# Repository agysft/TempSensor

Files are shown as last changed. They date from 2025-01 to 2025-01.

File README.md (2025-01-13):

# Temperature and humidity logger

This is a prototype of a device that records temperature and humidity to an SD card every hour.  
これは１時間毎に温度と湿度をSDカードに記録する装置の試作です。  
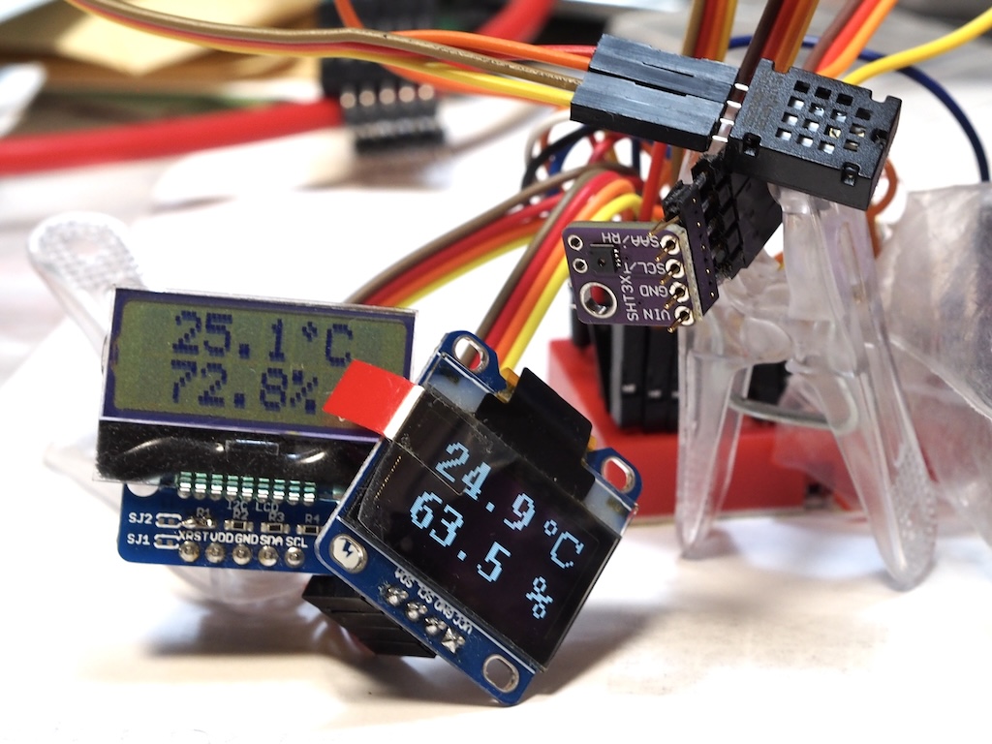
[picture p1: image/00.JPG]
  
It is actually a thermo-hygrometer to control the temperature of leopard geckos. It is intended to be hooked up to a breeding case.  
実はヒョウモントカゲモドキの温度管理をするための温湿度計です。
飼育ケースに引っ掛けて使うことを想定しています。
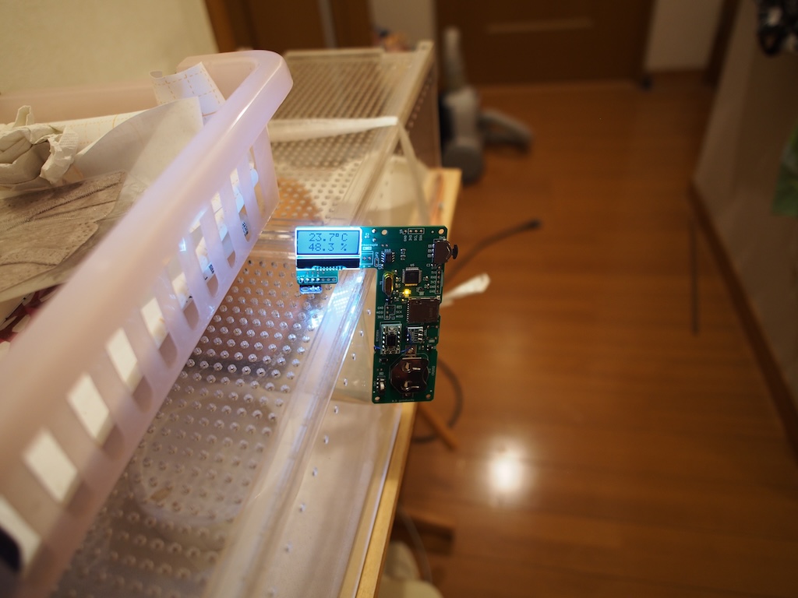
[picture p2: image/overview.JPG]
  
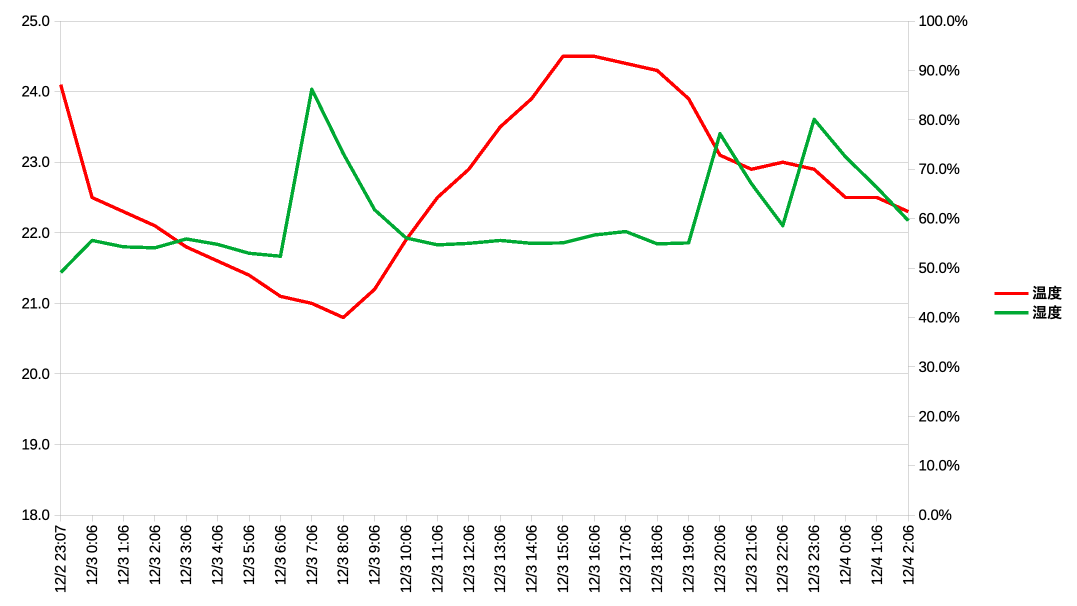
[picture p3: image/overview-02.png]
  
OLEDs can also be mounted. I chose Arduino base because it has a library of fonts.  
OLEDも載せられる様にしてます。その時フォントとか選びたいのでライブラリがあるArduinoベースにしました。  
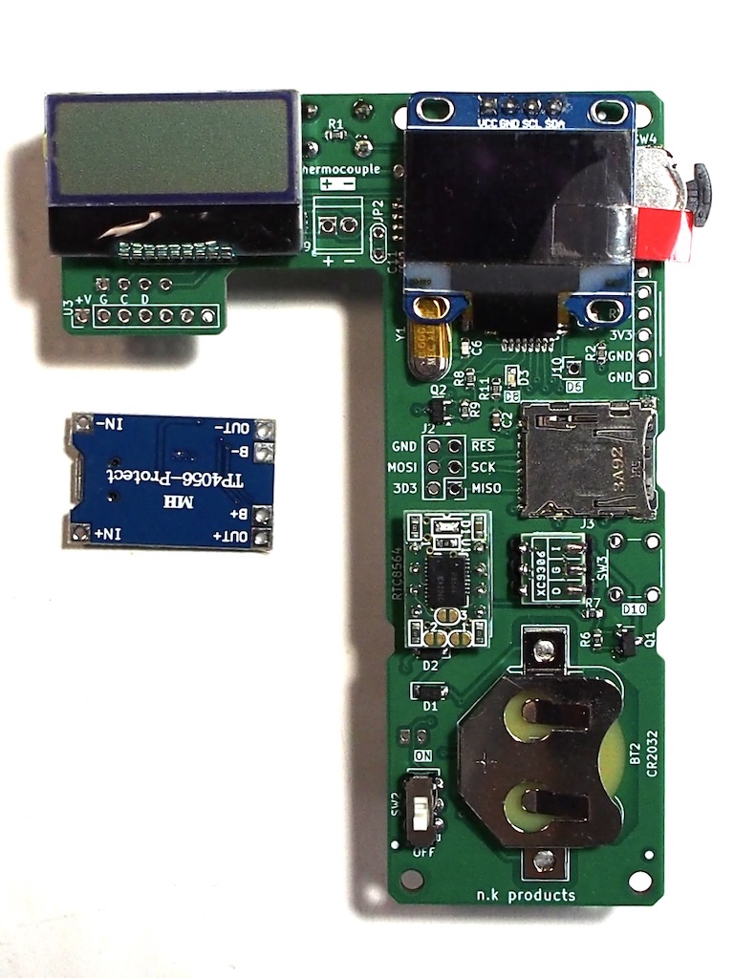
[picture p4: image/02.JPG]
  
The program was written in Arduino IDE. The schematic is written in KiCAD and the printed circuit board is made. The structure was made with a 3D printer.  
プログラムはArduino IDEで書きました。回路図はKiCADで書き、プリント基板を作っています。構造物は3Dプリンターで作りました。  

<image src="image/04-01.png" width="320px">
<image src="image/04-02.png" width="320px">
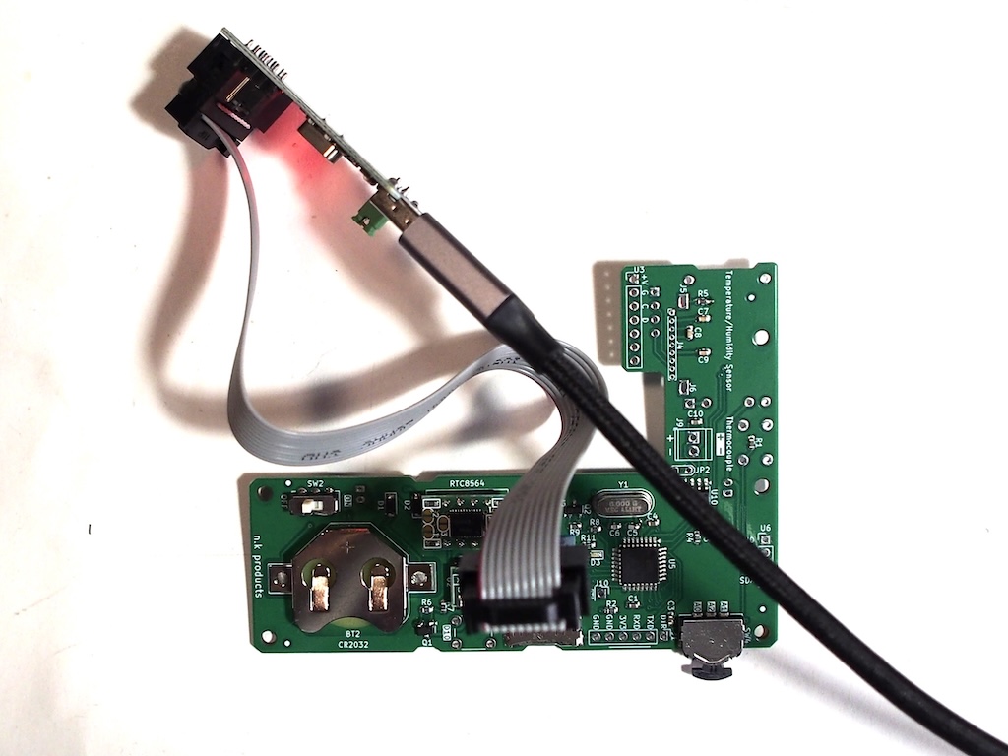
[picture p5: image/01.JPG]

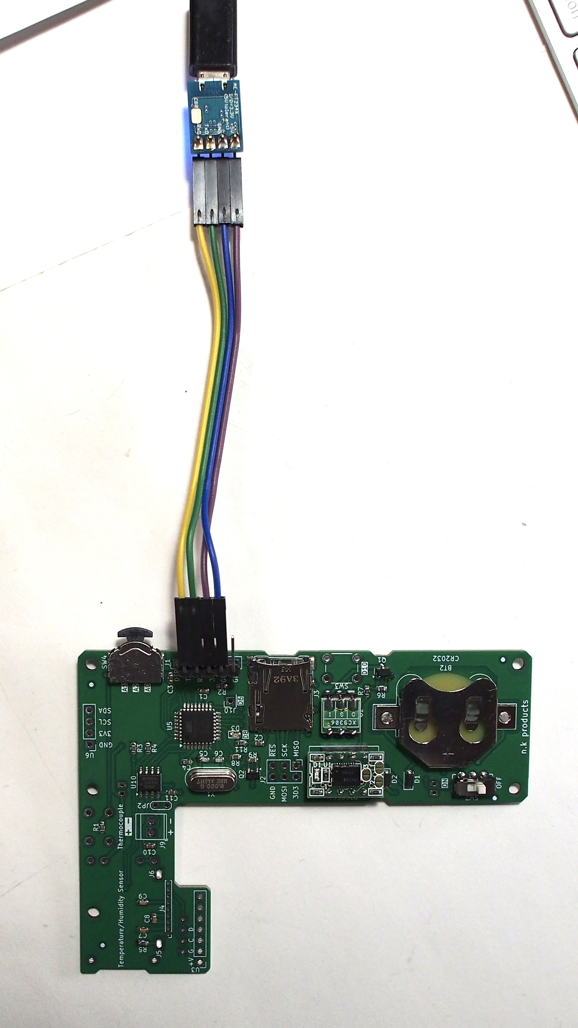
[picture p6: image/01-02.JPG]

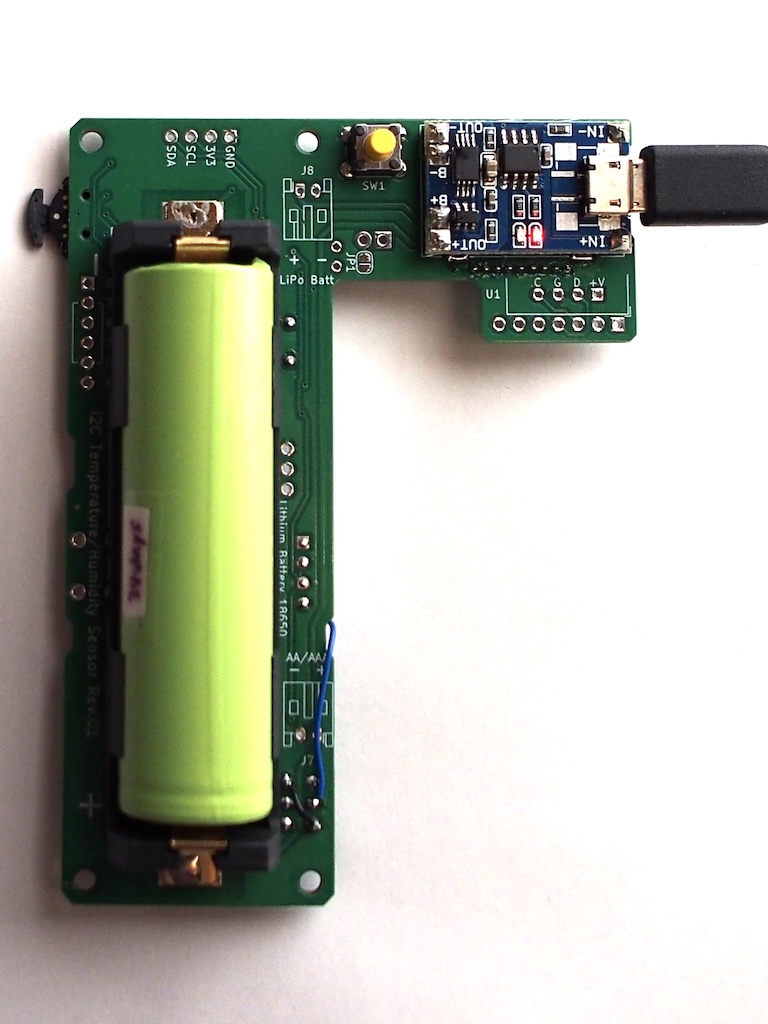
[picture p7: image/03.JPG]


---

* [schematics](schematics/TempHumiSensor.pdf)

The system is powered on and off at regular intervals by RTC and automatically turns off when the measurement is finished.  
RTCで一定時間毎に電源を入れて計測し、計測終了したら自動で電源を切る仕組みです。 

1. RTCで1時間毎に/INT信号を出す。RTC sends /INT signal every hour.
2. /INT信号がLowになると、Q1がOn=電源On。When the /INT signal goes Low, Q1 turns On = power supply On.
3. 電源がOnになると温湿度を測定する。  When the power supply is turned On, the temperature and humidity are measured.  
4. 測定終了したら/INTをクリア、Q1がOff=電源Off。  When measurement is completed, /INT is cleared and Q1 turns Off = power is Off.  

```mermaid
flowchart LR
    A[SHT31] -->|I2C| B[ATMEGA328P-AU]
    B --> |I2C|C[LCD]
    B -->|I2C| D[OLED]
    B -->|SPI| E[SD]
    F[MAX31855] -->|SPI| B
    G[LiPo Batt] -->|4V| H[Swich] --> I[Buck-Boost Converter] --- |3.3V|B
    J[RTC] --> |/INT|H
```

---

[modification document 改造資料]  
The P-ch MOS FET that turns the power supply On/Off could not be turned Off. The reason was that PD2 on the ATmega328P was pulling /POW low. I had to worry about leakage current flowing when the microcontroller was turned off.  
電源をOn/OffするP-ch MOS FETがOFFできなかった。理由はATmega328PのPD2が/POWをLowに引っ張っていたためです。マイコンの電源が切れている時は漏れ電流が流れる事を気にしなきゃならなかった。  
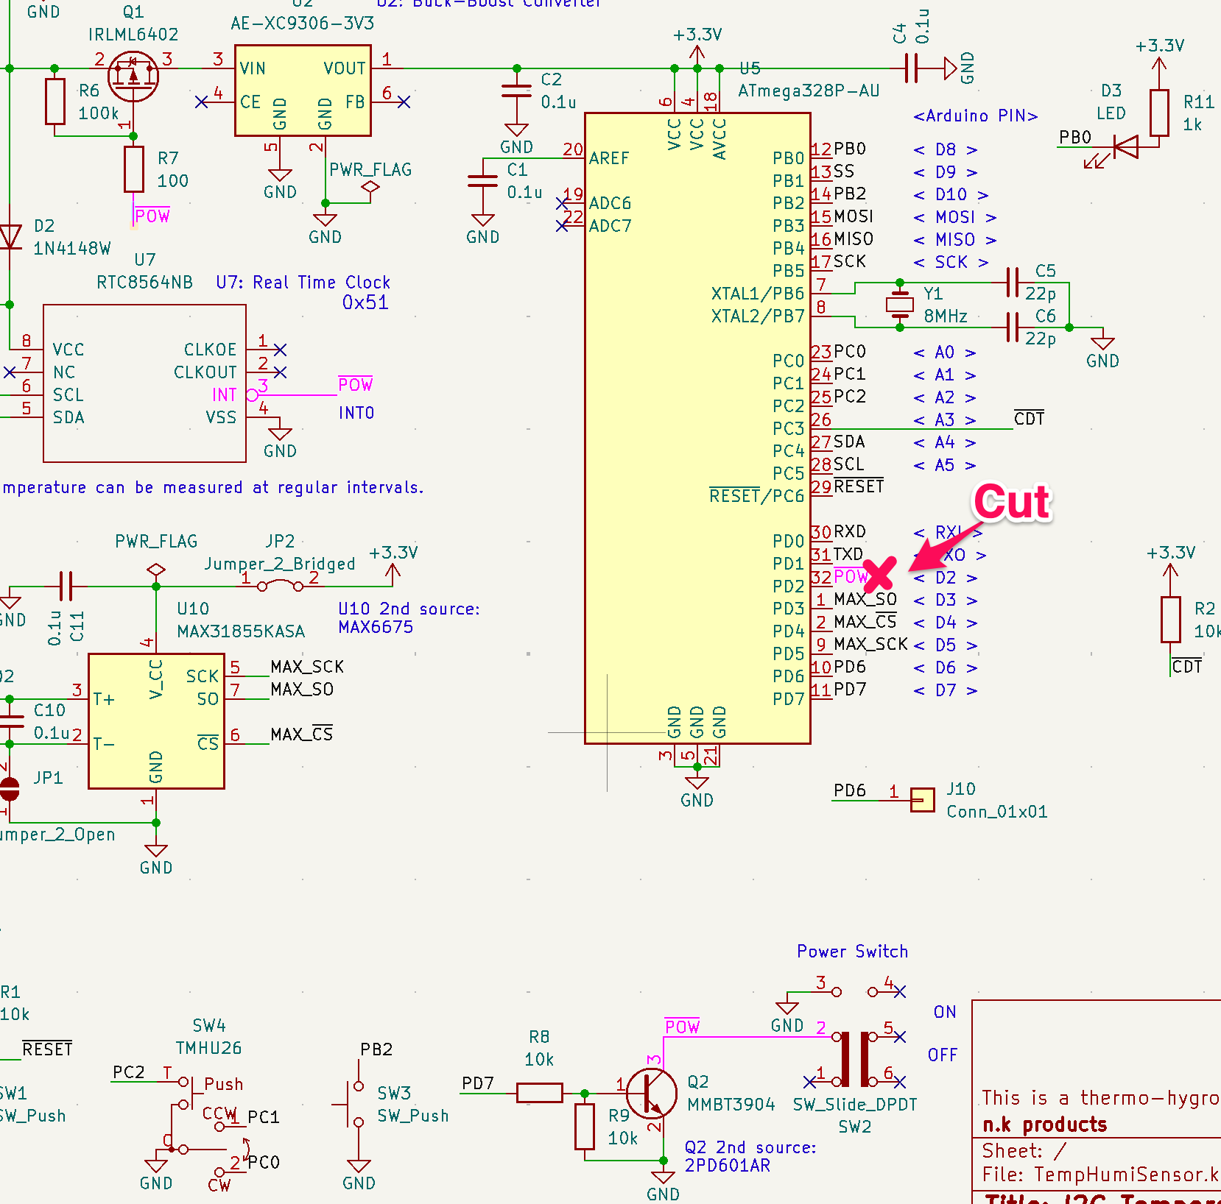
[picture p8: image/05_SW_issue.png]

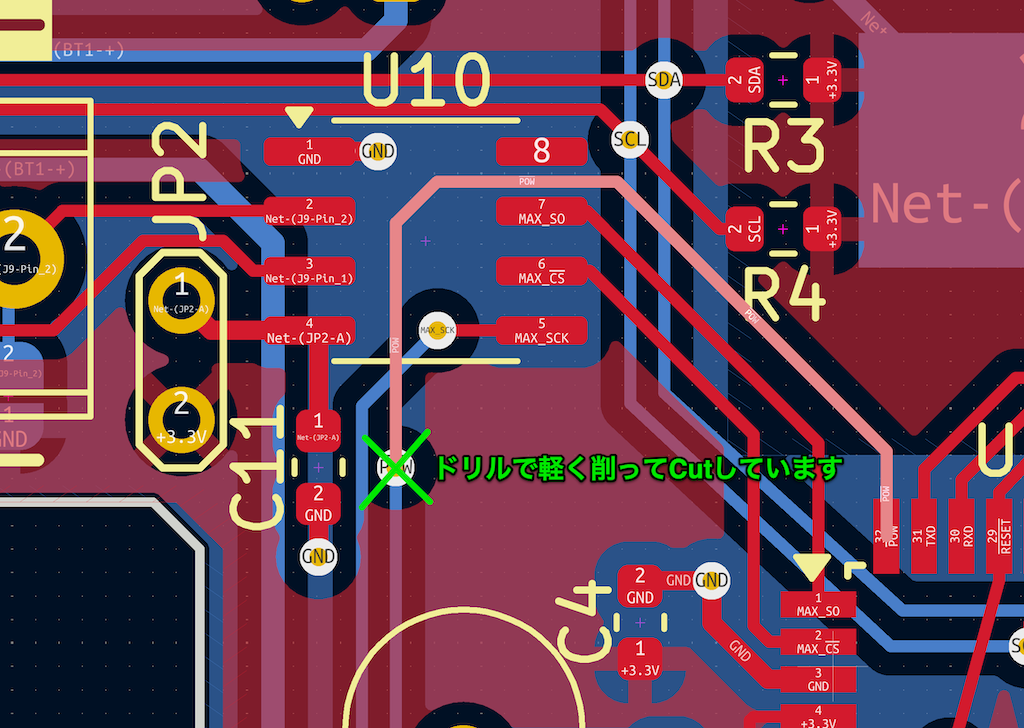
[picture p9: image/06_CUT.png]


---

[state diagram 状態遷移]
```mermaid
stateDiagram-v2
    s1: Power On
    s2: Write Temp/Humi data to SD card when TE=Enable
    s3: Display T/H sensor
    s4: Display Thermocouple
    s5: Display Clock
    s6: Adjust Clock
    s7: Timer Enable
    s8: Timer Disable
    s9: Shift Digit Up
    s10: Increment
    s11: Decrement
    s1 --> s2
    s2 --> s3
    s3 --> s4: push center-button
    s4 --> s5: push center-button
    s5 --> s3: push center-button
    s5 --> s6: long-push center-button
    s6 --> s5: long-push center-button
    s6 --> s9: push center-button
    s9 --> s6
    s6 --> s10: push up-button
    s10 --> s6
    s6 --> s11: push up-button
    s11 --> s6
    s7 --> s8: long-push push-button
    s8 --> s7: long-push push-button
```

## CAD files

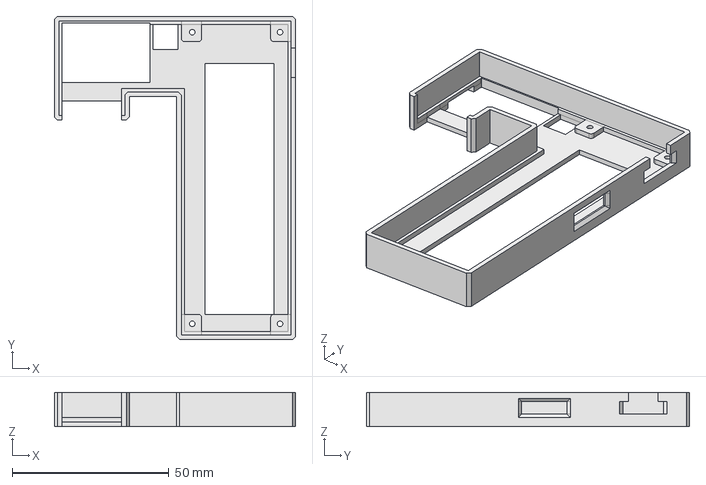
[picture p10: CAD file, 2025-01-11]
3D/tempSensor.FCStd
77.0 x 103.0 x 11.0 mm

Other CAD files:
3D/tempSensor-Body.stl

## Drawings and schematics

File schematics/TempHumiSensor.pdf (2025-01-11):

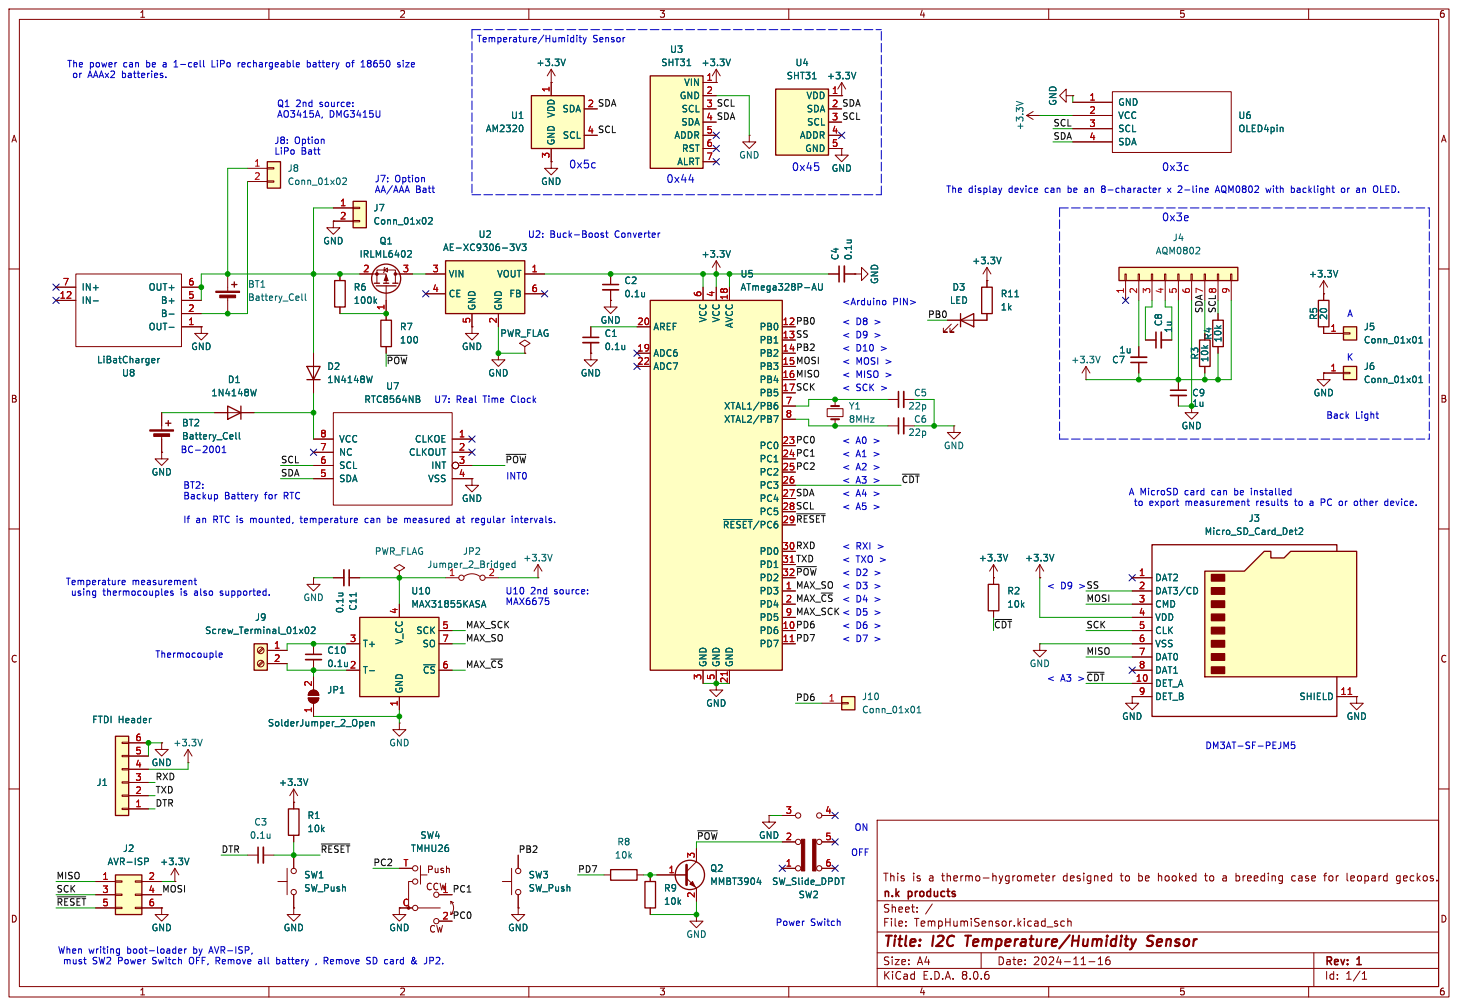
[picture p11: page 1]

3 SCL 4 +3.3V U3 SHT31VIN 1 GND 2 SCL 3 SDA 4 ADDR 5 RST 6 ALRT 7 +3.3V U4 SHT31VDD 1 SDA 2 SCL 3 ADDR 4 GND 5GND

BC-2001 BT2: Backup Battery for RTC

4 SCK 5 ~{CS}6 SO 7 0.1u C11 GND GND GND

4 SCK 5 ~{CS}6 SO 7 U10 MAX31855KASA CCW

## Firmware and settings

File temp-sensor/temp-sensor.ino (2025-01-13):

#include <Wire.h>
#include <SPI.h>
#include <SD.h>
//#include <EEPROM.h>
#include "RTC8564.h"

//#define SENSOR_MAX6675 //comment MAX31855
// Initialize the Thermocouple
// set pin of MAX31855,MAX6675
#define MAXDO   3
#define MAXCS   4
#define MAXCLK  5
#ifdef SENSOR_MAX6675
  #include "max6675.h"
  MAX6675 thermocouple(MAXCLK, MAXCS, MAXDO);
#else
  #include "Adafruit_MAX31855.h"
  Adafruit_MAX31855 thermocouple(MAXCLK, MAXCS, MAXDO);
#endif

float temperatureData = 0.0;  // Temperature

/*** OLED Definition ***/
//#define DISPLAY_OLED //comment No Use OLED
#ifdef DISPLAY_OLED
  #include <U8g2lib.h>
  U8G2_SSD1306_128X64_NONAME_1_HW_I2C u8g2(U8G2_R0, /* reset=*/ U8X8_PIN_NONE);
  #define OLED_ADDR 0x3C
#endif

/*** Enumerated I2C addresses ***/
uint8_t Enumerated_I2C_addresses[8];

/*** SD Card Definition ***/
#define SS_pin 9  // D9

/*** Switches Definition ***/
#define QTY_of_switches 4
#define sw_Upper 0
#define sw_Lower 1
#define sw_Center 2
#define sw_Push 3
struct SwitchStatus {
  uint8_t PinNumber;
  int Counter;
  bool Pressed;
  bool Released;
  bool LongPressing;
  bool LongPressed;
};
volatile struct SwitchStatus SW[QTY_of_switches];

/*** LCD ***/
#define LCD_ADDR 0x3e
char DisplayData[20] = "n.k     products    ";
void writeLCDData(byte t_data){
  Wire.beginTransmission(LCD_ADDR);
  Wire.write(0x40);
  Wire.write(t_data);
  Wire.endTransmission();
  delay(1);
}
void writeLCDCommand(byte t_command){
  Wire.beginTransmission(LCD_ADDR);
  Wire.write(0x00);
  Wire.write(t_command);
  Wire.endTransmission();
  delay(1);
}
void init_LCD(){
  delay(400);
  writeLCDCommand(0x38);
  writeLCDCommand(0x39);
  writeLCDCommand(0x14);
  writeLCDCommand(0x7c);
  writeLCDCommand(0x55);
  writeLCDCommand(0x6c);
  delay(250);
  writeLCDCommand(0x38);
  writeLCDCommand(0x01);
  writeLCDCommand(0x0c);
  delay(1);
}
void LCD_xy(uint8_t x, uint8_t y){
    writeLCDCommand(0x80 + 0x40 * y + x);
}
void LCD_str2(const char *c) {
    unsigned char wk;
    int i;
    for (i=0;i<8;i++){
        wk = c[i];
        if  (wk == 0x00) break;
        writeLCDData(wk);
    }
    delay(1);
}
void LCD_char(char wk) {
  writeLCDData(wk);
  delay(1);
}
void LCD_char_with_Cursor(uint8_t x, uint8_t y, char wk) {
  writeLCDCommand(0x80 + 0x40 * y + x);
  writeLCDData(wk);
  LCD_cursor_Left();
  delay(1);
}
void LCD_clear(){
  writeLCDCommand(0x01);
  delay(1);
}
void LCD_cursor_on(){
  writeLCDCommand(0b00001111);
  //writeLCDCommand(0b00010000);  // bit3=S/C=L, bit2=R/K=L
  delay(1);
}
void LCD_cursor_off(){
  writeLCDCommand(0b00001100);
  delay(1);
}
void LCD_cursor_Left(){
  writeLCDCommand(0b00010000);
  delay(1);
}
void LCD_cursor_Right(){
  writeLCDCommand(0b00010100);
  delay(1);
}

/*** SHT31 ***/
#define SHT31_ADDR 0x44
int TData, HData;  //Temp data , Humi data
uint8_t THData[6];
/*
THData[0] temperature high
THData[1] temperature low
THData[2] CRC temperature
THData[3] humidity high
THData[4] humidity low
THData[5] CRC humidity
 */
void readSHT31(){
  Wire.beginTransmission(SHT31_ADDR);
  Wire.write(0x24);
  Wire.write(0x00);
  Wire.endTransmission();
  delay(30);  // 12=NG, 13=Good
  Wire.requestFrom(SHT31_ADDR, 6);
  for (int i=0; i<6; i++){
    THData[i] = Wire.read();
  }
}
void getTH(){
  long lTData, lHData;
  readSHT31();
  lTData = 256 * THData[0] + THData[1];
  lTData = -450 + (1750 * lTData) / 65535;
  TData = (int)lTData;
  lHData = (long)(THData[3]);
  lHData = (lHData << 8) | THData[4];
  lHData = (1000 * lHData) / 65535;
  HData = (int)lHData;
}
void DispTH(){
  byte x, x2;
  float T2Data,H2Data;
  getTH();
  #ifdef DISPLAY_OLED
    if (isAaddressExistInI2C(OLED_ADDR)){
      u8g2.clearBuffer();
      u8g2.firstPage();
      do {
        /* all graphics commands have to appear within the loop body. */
        T2Data = (float)TData; dtostrf(T2Data/10,4,1,DisplayData);
        x = u8g2.drawStr(0,25,DisplayData);
        x2 = u8g2.drawStr(x,25," C");//"\xB0"); 
        //u8g2.drawStr(x+x2,15,"C");
        H2Data = (float)HData; dtostrf(H2Data/10,4,1,DisplayData);
        x = u8g2.drawStr(0,63,DisplayData); u8g2.drawStr(x,63," %");
      } while ( u8g2.nextPage() );
      u8g2.sendBuffer();
    }
  #endif
  sprintf(DisplayData, "%3d.%1d C\0", TData /10, abs(TData %10) );//"%3d.%1d\xDF\x43", TData /10, abs(TData %10) );
  LCD_xy(0,0); LCD_str2( DisplayData );
  sprintf(&DisplayData[8], " %2d.%1d %%\0", HData /10, HData %10 );
  LCD_xy(0,1); LCD_str2( &DisplayData[8] );
}

/*** Read Thermocouple ***/

void ReadThermocouple(void) {
  float temp = 0.0;  // Temperature
  for (byte i = 0; i < 5; i++) {
      do {
      temperatureData = thermocouple.readCelsius();
    }while(isnan(temperatureData)) ;
        
    temp = temp + temperatureData;
    delay(20);
  }
  #ifdef SENSOR_MAX6675
    temperatureData = (temp / 5.0)*0.99 -2.5;  //MAX6675
    //if ( temperatureData > 200 ) temperatureData-10;
  #else
    temperatureData = (temp / 5.0)*1.00-1.0;  //MAX31855
  #endif
}

/*** RTC8564 ***/
#define RTC8564_SLAVE_ADRS 0x51
bool TimerEnable = false;
uint8_t date_time[7];
/*date_time[0] = 0x00;//seconds
date_time[1] = 0x45;//minutes
date_time[2] = 0x17;//hours
date_time[3] = 0x28;//days
date_time[4] = 0x04;//weekdays
date_time[5] = 0x11;//months/century
date_time[6] = 0x24;//years*/
void writeCommandToRTC(uint8_t reg1, uint8_t dat1){
  Wire.beginTransmission(RTC8564_SLAVE_ADRS);
  Wire.write(reg1);
  Wire.write(dat1);
  Wire.endTransmission();
}
uint8_t readRegDataFromRTC(uint8_t reg1){
  Wire.beginTransmission(RTC8564_SLAVE_ADRS);
  Wire.write(reg1);
  Wire.endTransmission();
  Wire.requestFrom(RTC8564_SLAVE_ADRS, 1);
  if( Wire.available() ){
    return( Wire.read() );
  } else {
    return 0xff;
  }
}
// 60分間隔で/INT信号を繰り返しLOWにする
void generateINTeveryHour(void){
  writeCommandToRTC(0x0e, 0b00000011); // TE bit7 = 0 Stop Timer; TD bit0-1 0b11 = 1 minuts, 0b10 = 1second
  writeCommandToRTC(0x01, 0b00000001); // TI/TP = 0 Level INT mode; TF = 0 INT Hi-z; TIE = 1 Enable INT
  writeCommandToRTC(0x0f, 60);         // (TD bit * 60)
  writeCommandToRTC(0x0e, 0b10000011); // TE bit7 = 1 Start Timer; TD bit0-1 0b11 = 1 minuts, 0b10 = 1second
}
// /INTをクリアする = 電源OFF
void clearINT(void){
  delay(500); // Delay 500ms
  writeCommandToRTC(0x01, 0b00000001); // TF = 0 clear INT -> Power Off; TI/TP = 0; TIE = 1
}
// TE(Timer Enable) bitをクリアする
void endTimerOperation(void){
  writeCommandToRTC(0x0e, 0b00000011); // TE bit7 = 0 Stop Timer; TD bit0-1 0b11 = 1 minuts, 0b10 = 1second
}
// TE bitを読み出す
bool readTEbit(){
  if ( (readRegDataFromRTC(0x0e) & 0b10000000) != 0 ){
    return true;
  } else {
    return false;
  }
}
#define AAMinute 1
#define AAHour  2
#define AADay   3
#define AAWeek  4
#define AAMonth 5
#define AAYear  6
void LoadTimeValuesIntoArray(){
  date_time[AAMinute] = Rtc.minutes();
  date_time[AAHour] = Rtc.hours();
  date_time[AADay] = Rtc.days();
  date_time[AAWeek] = Rtc.weekdays();
  date_time[AAMonth] = Rtc.months();
  date_time[AAYear] = Rtc.years();
}
void SaveArrayValuesIntoRTC(){
  Rtc.sync( date_time, 7 );
}

/*** SD Card ***/
bool CardDetect(){
  if (digitalRead(A3) == LOW){
    return true;
  } else {
    return false;
  }
}

// 現在時刻をLCDに表示する
const char* Weekdays[]={"Su","Mo","Tu","Wd","Th","Fr","Sa"};
void DispCurrentTime(){
  Rtc.available();  //read RTC data
  if (isAaddressExistInI2C(LCD_ADDR)){
    LCD_clear();
    DisplayData[0] = (Rtc.years() >> 4) + 0x30;
    DisplayData[1] = (Rtc.years() & 0x0f) + 0x30;
    DisplayData[2] = ' '; 
    DisplayData[3] = (Rtc.months() >> 4) + 0x30;
    DisplayData[4] = (Rtc.months() & 0x0f) + 0x30;
    DisplayData[5] = '/';
    DisplayData[6] = (Rtc.days() >> 4) + 0x30;
    DisplayData[7] = (Rtc.days() & 0x0f) + 0x30;
    DisplayData[8] = 0;
    LCD_xy(0,0); LCD_str2( DisplayData );
    DisplayData[0] = *Weekdays[Rtc.weekdays()];
    DisplayData[1] = *(Weekdays[Rtc.weekdays()]+1);
    DisplayData[3] = (Rtc.hours() >> 4) + 0x30;
    DisplayData[4] = (Rtc.hours() & 0x0f) + 0x30;
    DisplayData[5] = ':';
    DisplayData[6] = (Rtc.minutes() >> 4) + 0x30;
    DisplayData[7] = (Rtc.minutes() & 0x0f) + 0x30;
    DisplayData[8] = 0;
    LCD_xy(0,1); LCD_str2( DisplayData );
  }
}
// 現在時刻と温湿度をSDに書き出す
void writeCurrentTimeAndTemp(){
  char WriteData[18]="2024/11/18 15:55\0";
  Rtc.available();  //read RTC data
  WriteData[2]=(Rtc.years() >> 4) + 0x30;
  WriteData[3]=(Rtc.years() & 0x0f) + 0x30;
  WriteData[5]=(Rtc.months() >> 4) + 0x30;
  WriteData[6]=(Rtc.months() & 0x0f) + 0x30;
  WriteData[8]=(Rtc.days() >> 4) + 0x30;
  WriteData[9]=(Rtc.days() & 0x0f) + 0x30;
  WriteData[11]=(Rtc.hours() >> 4) + 0x30;
  WriteData[12]=(Rtc.hours() & 0x0f) + 0x30;
  WriteData[14]=(Rtc.minutes() >> 4) + 0x30;
  WriteData[15]=(Rtc.minutes() & 0x0f) + 0x30;
  WriteData[16]=0;

  getTH();
  sprintf(DisplayData, ",%3d.%1d C, %2d.%1d %%,\n\0", TData /10, abs(TData %10), HData /10, HData %10 );
  
  Serial.print(WriteData);  // for test
  Serial.print(DisplayData);  // for test
  Serial.println(temperatureData);  // for test
  if ( CardDetect() ) {
    pinMode(SS_pin, OUTPUT);
    pinMode(10, OUTPUT);//pinMode(10, INPUT_PULLUP);
    delay(20);
    if (!SD.begin(SS_pin)) {
      Serial.println("SD init failed!");
      //while (1);
      return;
    } else Serial.println("SD init done.");
    delay(20);  // SD.beginの後、SD.openの前にwaitが要るっぽい。grobal data DisplayDataまたはWriteDataの一部が文字化けすることがある。
    File myFile = SD.open("LOG.TXT");//for test
    myFile.close();
    for (int i = 0; i < 10; i++ ){  // for test
        delay(500);
      myFile = SD.open("LOG.TXT", FILE_WRITE);
      if (myFile) {
        Serial.print("Writing to LOG...");
        //delay(20);
        myFile.write(WriteData, 16);
        myFile.write(DisplayData, 17);
        myFile.println(temperatureData);
        myFile.close();
        Serial.println("done.");
        /* Regarding the problem of failing to Begin SD every other time, it will no longer occur if you READ it once here. */
        myFile = SD.open("LOG.TXT", FILE_WRITE);
        myFile.close();
        break;
      } else {
        // if the file didn't open, print an error:
        Serial.print(" *");//ln("error opening log.txt");
      }
      if (i == 9) Serial.println(" error opening LOG");
    }
  } else {
    Serial.println("No SD found.");    
  }
  delay(100);
  digitalWrite(SS_pin, HIGH); // SS_pin inactive
  pinMode(10, INPUT_PULLUP);
}

/* Enumerate I2C addresses */
int ScanI2C(){
  int nDevices = 0;
  // 0x3C : OLED Akizuki
  // 0x3E : LCD AQM0802
  // 0x44 : Temp/Humi Sensor SHT31
  // 0x51 : RTC8564
  for (byte i = 0; i < 8; ++i) {
    Enumerated_I2C_addresses[i] = 0;
  }
  Serial.println("I2C Scanning...");
  for (byte address = 1; address < 127; ++address) {
    // The i2c_scanner uses the return value of
    // the Wire.endTransmission to see if
    // a device did acknowledge to the address.
    Wire.beginTransmission(address);
    byte error = Wire.endTransmission();
    if (error == 0) {
      Serial.print("I2C device found 0x");
      if (address < 16) {
        Serial.print("0");
      }
      Serial.print(address, HEX);
      Serial.println("  !");
      ++nDevices;
      Enumerated_I2C_addresses[nDevices] = address;
    } else if (error == 4) {
      Serial.print("Unknown error 0x");
      if (address < 16) {
        Serial.print("0");
      }
      Serial.println(address, HEX);
    }
  }
  if (nDevices == 0) {
    Serial.println("No I2C found\n");
  } else {
    Serial.println("done");
  }
  return nDevices;
}
bool isAaddressExistInI2C(uint8_t address_to_look_for){
  for (int i=0;i<8;i++){
      if(Enumerated_I2C_addresses[i] == address_to_look_for){
        return true;
      }
  }
  return false;  
}

/*** get switch status ***/
void getSwitchStatus(){
  for (int i=0; i < QTY_of_switches; i++){
    if (digitalRead(SW[i].PinNumber) == LOW){
      SW[i].Counter++;
      SW[i].Released = false;
      if (SW[i].Counter > 1000) SW[i].LongPressing = true;
    } else {
      SW[i].Released = true;
      if ( (SW[i].Counter > 10) && (SW[i].Counter < 1000) ) {
        SW[i].Pressed = true;
      } else SW[i].Pressed = false;
      if (SW[i].Counter > 1000) SW[i].LongPressed = true;
      SW[i].Counter = 0;   
    }
  }
}

/*** clear switch status ***/
void clearSwitchStatus(){
  for (int i=0; i < QTY_of_switches; i++){
    SW[i].Counter = 0;
    SW[i].LongPressing = false;
    SW[i].LongPressed = false;
    SW[i].Released = true;
    SW[i].Pressed = false;
  }
}

/*** Digit High/Low Up/Down ***/
void digitHUp(uint8_t x, uint8_t y, int DateTimeSelect, int MaxDigitValue){
  date_time[DateTimeSelect] += 0x10; if ( date_time[DateTimeSelect] >= MaxDigitValue ) date_time[DateTimeSelect] -= MaxDigitValue;
  LCD_char_with_Cursor(x,y, (date_time[DateTimeSelect] >> 4) + 0x30 );
}
void digitHDown(uint8_t x, uint8_t y, int DateTimeSelect, int MaxDigitValue){
  uint8_t tmpDT;
  tmpDT = date_time[DateTimeSelect];
  tmpDT = (tmpDT & 0xF0) -0x10; if ( tmpDT == 0xF0 ) tmpDT = MaxDigitValue -0x10;
  date_time[DateTimeSelect] = (date_time[DateTimeSelect] & 0x0F) | tmpDT;
  LCD_char_with_Cursor(x,y, (date_time[DateTimeSelect] >> 4) + 0x30 );
}
void digitLUp(uint8_t x, uint8_t y, int DateTimeSelect){ // minute:9, hour:9, day:9, month:9, year:9
  date_time[DateTimeSelect] += 1; if ( (date_time[DateTimeSelect] & 0x0f) > 9 ) date_time[DateTimeSelect] = date_time[DateTimeSelect] & 0xF0;
  LCD_char_with_Cursor(x,y, (date_time[DateTimeSelect] & 0x0f) + 0x30 );
}
void digitLDown(uint8_t x, uint8_t y, int DateTimeSelect){
  uint8_t tmpDT;
  tmpDT = date_time[DateTimeSelect];
  tmpDT = (tmpDT & 0x0f) -1; if ( tmpDT == 0xFF ) tmpDT = 9;
  date_time[DateTimeSelect] = (date_time[DateTimeSelect] & 0xF0) | tmpDT; 
  LCD_char_with_Cursor(x,y, (date_time[DateTimeSelect] & 0x0f) + 0x30 );
}
void digitWUp(uint8_t x, uint8_t y, int DateTimeSelect){
  date_time[DateTimeSelect] += 1; if ( date_time[DateTimeSelect] > 6 ) date_time[DateTimeSelect] = 0;
  LCD_char_with_Cursor(x,y, *Weekdays[date_time[DateTimeSelect]] );
  LCD_char_with_Cursor(x+1,y, *(Weekdays[date_time[DateTimeSelect]]+1) );
}
void digitWDown(uint8_t x, uint8_t y, int DateTimeSelect){
  date_time[DateTimeSelect] -= 1; if ( date_time[DateTimeSelect] == 0xFF ) date_time[DateTimeSelect] = 6;
  LCD_char_with_Cursor(x,y, *Weekdays[date_time[DateTimeSelect]] );
  LCD_char_with_Cursor(x+1,y, *(Weekdays[date_time[DateTimeSelect]]+1) );
}
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
void loop() {
  // Get Switches status
  getSwitchStatus();

  //　Processes once every two seconds.
  if( PollingCounter == 0 ){
    switch (StateOfDisplay){
      case DispSensor:      // Display temperature and humidity
        LCD_cursor_off();
        DispTH();
        clearINT(); //If don't clear INT, stays power-on all the time.
        break;

      case DispThermocouple:
        ReadThermocouple();
        sprintf(DisplayData, "%3d.%02d C  \n\0", (int)temperatureData, abs( (int)(temperatureData*100) % 100) );  // With Arduino, %f is not available.
        LCD_xy(0,0); LCD_str2( DisplayData );
        break;
        
      case DispClock:       // Display Clock
        DispCurrentTime();
        clearINT(); //If don't clear INT, stays power-on all the time.
        break;
        
      case AdjustClock:     // Does nothing while setting the time.
        break;
    }    
  }
  
  //Long press on yellow button to Toggle On/Off INT Timer
  if (SW[sw_Push].LongPressed) {
    if ( readTEbit() ){
      endTimerOperation();
      digitalWrite(8, HIGH);  // Turn off LED
    } else {
      generateINTeveryHour();
      digitalWrite(8, LOW);  // Turn-on the LED
    }
    SW[sw_Push].LongPressed = false;
    SW[sw_Push].LongPressing = false;
    SW[sw_Push].Pressed = false;
  }
  
  if (SW[sw_Push].LongPressing) {
    LCD_clear();
    SW[sw_Push].LongPressed = false;
    SW[sw_Push].Pressed = false;
  }
  
  //Press Center button to switch display 0:temperature or 1:clock
  if (SW[sw_Center].Pressed && (StateOfDisplay != AdjustClock) ){
    LCD_clear();
    switch ( StateOfDisplay ){
      case DispSensor:
        StateOfDisplay = DispThermocouple;
        break;
      case DispThermocouple:
        StateOfDisplay = DispClock;
        break;
      case DispClock:
        StateOfDisplay = DispSensor;
        break;
    }
    SW[sw_Center].LongPressed = false;
    SW[sw_Center].Pressed = false;
    PollingCounter = 1999;
  }
  //Press Center button to switch AdjustEachDigitOfClock
  if (SW[sw_Center].Pressed && (StateOfDisplay == AdjustClock) ){
    AdjustEachDigitOfClock--;
    if (AdjustEachDigitOfClock < 0) AdjustEachDigitOfClock = 10;
    switch (AdjustEachDigitOfClock) {
      case AYearH:  LCD_char_with_Cursor(0,0, (date_time[AAYear] >> 4) + 0x30 );  break;
      case AYearL:  LCD_char_with_Cursor(1,0, (date_time[AAYear] & 0x0f) + 0x30 );break;
      case AMonthH: LCD_char_with_Cursor(3,0, (date_time[AAMonth] >> 4) + 0x30 ); break;
      case AMonthL: LCD_char_with_Cursor(4,0, (date_time[AAMonth] & 0x0f) + 0x30 );break;
      case ADayH:   LCD_char_with_Cursor(6,0, (date_time[AADay] >> 4) + 0x30 );   break;
      case ADayL:   LCD_char_with_Cursor(7,0, (date_time[AADay] & 0x0f) + 0x30 ); break;
      case AWeek:
        LCD_char_with_Cursor(0,1, *Weekdays[date_time[AAWeek]] );
        LCD_char_with_Cursor(1,1, *(Weekdays[date_time[AAWeek]]+1) );
        break;
      case AHourH:  LCD_char_with_Cursor(3,1, (date_time[AAHour] >> 4) + 0x30 );  break;
      case AHourL:  LCD_char_with_Cursor(4,1, (date_time[AAHour] & 0x0f) + 0x30 );break;
      case AMinutH: LCD_char_with_Cursor(6,1, (date_time[AAMinute] >> 4) + 0x30 );break;
      case AMinutL: LCD_char_with_Cursor(7,1, (date_time[AAMinute] & 0x0f) + 0x30 );break;
    }
    SW[sw_Center].LongPressed = false;
    SW[sw_Center].Pressed = false;
    SW[sw_Center].Counter = 0;
    //PollingCounter = 1999;
  }
  //Long-press on center button to adjust clock
  if ( SW[sw_Center].LongPressed ){
    switch ( StateOfDisplay ){
      case DispClock:
        StateOfDisplay = AdjustClock;
        LCD_cursor_on();
        LoadTimeValuesIntoArray();
        AdjustEachDigitOfClock = AMinutL;
        LCD_char_with_Cursor(7,1, (date_time[AAMinute] & 0x0f) + 0x30 );
        break;
      case AdjustClock:
        /*** Set the time on RTC ***/
        StateOfDisplay = DispClock;
        SaveArrayValuesIntoRTC();
        break;
    }
    SW[sw_Center].LongPressing = false;
    SW[sw_Center].LongPressed = false;
    SW[sw_Center].Pressed = false;
    PollingCounter = 1999;
  }
  if ( SW[sw_Center].LongPressing ){
    if(StateOfDisplay != DispClock) LCD_clear();
  }  

  //Press sw_Lower / sw_Upper on AdjustClock mode
  if ( StateOfDisplay == AdjustClock ){
    if ( SW[sw_Lower].Pressed ){
      switch (AdjustEachDigitOfClock) {
        case AYearH:  digitHDown(0, 0, AAYear, 0xA0); break;
        case AYearL:  digitLDown(1, 0, AAYear);       break;
        case AMonthH: digitHDown(3, 0, AAMonth, 0x20);break;
        case AMonthL: digitLDown(4, 0, AAMonth);      break;
        case ADayH:   digitHDown(6, 0, AADay, 0x40);  break;
        case ADayL:   digitLDown(7, 0, AADay);        break;
        case AWeek:   digitWDown(0, 1, AAWeek);       break;
        case AHourH:  digitHDown(3, 1, AAHour, 0x30); break;
        case AHourL:  digitLDown(4, 1, AAHour);       break;
        case AMinutH: digitHDown(6, 1, AAMinute, 0x60); break;
        case AMinutL: digitLDown(7, 1, AAMinute);     break;
      }
      SW[sw_Lower].Counter = 0;
      SW[sw_Lower].Pressed = false;
      SW[sw_Lower].LongPressed = false;
    }
    if ( SW[sw_Upper].Pressed ){
      switch (AdjustEachDigitOfClock) {
        case AYearH:  digitHUp(0, 0, AAYear, 0xA0); break;
        case AYearL:  digitLUp(1, 0, AAYear);       break;
        case AMonthH: digitHUp(3, 0, AAMonth, 0x20);break;
        case AMonthL: digitLUp(4, 0, AAMonth);      break;
        case ADayH:   digitHUp(6, 0, AADay, 0x40);  break;
        case ADayL:   digitLUp(7, 0, AADay);        break;
        case AWeek:   digitWUp(0, 1, AAWeek);       break;
        case AHourH:  digitHUp(3, 1, AAHour, 0x30); break;
        case AHourL:  digitLUp(4, 1, AAHour);       break;
        case AMinutH: digitHUp(6, 1, AAMinute, 0x60); break;
        case AMinutL: digitLUp(7, 1, AAMinute);     break;
      }
      SW[sw_Upper].Counter = 0; 
      SW[sw_Upper].Pressed = false;
      SW[sw_Upper].LongPressed = false;
    }
  }

  PollingCounter++;
  if (PollingCounter > 1999) {
    PollingCounter = 0;
  }
  delay(1);
}

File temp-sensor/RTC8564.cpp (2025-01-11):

extern "C" {
  #include <stdlib.h>
  #include <string.h>
  #include <inttypes.h>
}
//#include <WConstants.h>
#include <Arduino.h>
#include <Wire.h>
#include "RTC8564.h"

#define RTC8564_SLAVE_ADRS	(0xA2 >> 1)
//#define BCD2Decimal(x)		(((x>>4)*10)+(x&0xf))

// Constructors ////////////////////////////////////////////////////////////////

RTC8564::RTC8564()
	: _seconds(0), _minutes(0), _hours(0), _days(0), _weekdays(0), _months(0), _years(0), _century(0)
{
}

void RTC8564::init(void)
{
	delay(100); //cut&try
	Wire.beginTransmission(RTC8564_SLAVE_ADRS);
	Wire.write(0x00);			// write reg addr 00
	Wire.write(0x20);			// 00 Control 1, STOP=1
	Wire.write(0x00);			// 01 Control 2
	Wire.write(0x00);			// 02 Seconds
	Wire.write(0x00);			// 03 Minutes
	Wire.write(0x09);			// 04 Hours
	Wire.write(0x01);			// 05 Days
	Wire.write(0x01);			// 06 Weekdays
	Wire.write(0x01);			// 07 Months
	Wire.write(0x01);			// 08 Years
	Wire.write(0x00);			// 09 Minutes Alarm
	Wire.write(0x00);			// 0A Hours Alarm
	Wire.write(0x00);			// 0B Days Alarm
	Wire.write(0x00);			// 0C Weekdays Alarm
	Wire.write(0x00);			// 0D CLKOUT
	Wire.write(0x00);			// 0E Timer control
	Wire.write(0x00);			// 0F Timer
	Wire.write(0x00);			// 00 Control 1, STOP=0
	Wire.endTransmission();
}

// Public Methods //////////////////////////////////////////////////////////////

// An interrupt occurs every ten minutes
void RTC8564::INT10Minutes(void)
{
	delay(10); //cut&try
    Wire.beginTransmission(RTC8564_SLAVE_ADRS);
	Wire.write(0x01);			// write reg addr 01 "Control 2"
    Wire.write(0b00010001);     // TI/TP=1, AIE=0, TIE=1
    Wire.endTransmission();

	Wire.beginTransmission(RTC8564_SLAVE_ADRS);
	Wire.write(0x0F);			// write reg addr 0F "Timer"
    Wire.write(10);             // 10 minutes
    Wire.endTransmission();

    Wire.beginTransmission(RTC8564_SLAVE_ADRS);
	Wire.write(0x0E);			// write reg addr 0E "Timer Control"
    Wire.write(0b10000011);     // TE=1 & source clk is 1 minutes
    Wire.endTransmission();
}

// interrupt occurs every x0 minutes
void RTC8564::INT10Minutes2(void)
{
	uint8_t Minutes10;
    delay(10); //cut&try
    // clear INT
    Wire.beginTransmission(RTC8564_SLAVE_ADRS);
	Wire.write(0x01);			// write reg addr 01 "Control 2"
    Wire.write(0b00000000);     // AIE=0 (INT = High), Clear AF bit
    Wire.endTransmission();
    delay(10); //cut&try
    // read minutes
    Wire.beginTransmission(RTC8564_SLAVE_ADRS);
	Wire.write(0x03);			// write reg addr 03 = Minutes
	Wire.endTransmission(false);
	Wire.requestFrom(RTC8564_SLAVE_ADRS, 1);
    Minutes10 = Wire.read();
    Minutes10 = (Minutes10 & 0x7f) >> 4;
    Minutes10++;
    if ( Minutes10 > 5){
        Minutes10 = 0;
    }
    Minutes10 = Minutes10 << 4;

    // Wire.beginTransmission(RTC8564_SLAVE_ADRS);
	// Wire.write(0x0E);			// write reg addr 0E "Timer Control"
    // Wire.write(0b00000000);     // TE=0 Timer Disable
    // Wire.endTransmission();
    delay(10); //cut&try
	Wire.beginTransmission(RTC8564_SLAVE_ADRS);
	Wire.write(0x09);			// write reg addr 0F "Timer"
    Wire.write(Minutes10);      // set Minute Alarm ( now minutes + 10 minutes)
    Wire.write(0b10000000);     // mask Hour Alarm
    Wire.write(0b10000000);     // mask Day Alarm
    Wire.write(0b10000000);     // mask Weekday Alarm
    Wire.endTransmission();

    Wire.beginTransmission(RTC8564_SLAVE_ADRS);
	Wire.write(0x01);			// write reg addr 01 "Control 2"
    Wire.write(0b00000010);     // AIE=1(Ready for next INT)
    Wire.endTransmission();
}

// interrupt occurs every 00 second
void RTC8564::INT00Sec(void)
{
    delay(10); //cut&try
    Wire.beginTransmission(RTC8564_SLAVE_ADRS);
	Wire.write(0x0E);			// write reg addr 0E "Timer Control"
    Wire.write(0b00000000);     // TE=0 Timer Disable
    Wire.endTransmission();

    Wire.beginTransmission(RTC8564_SLAVE_ADRS);
	Wire.write(0x01);			// write reg addr 01 "Control 2"
    Wire.write(0b00010001);     // TI/TP=1, AIE=0, TIE=1, Clear AF bit
    Wire.endTransmission();

	Wire.beginTransmission(RTC8564_SLAVE_ADRS);
	Wire.write(0x0e);			// write reg addr 0E
    Wire.write(0b10000011);     // TE=1,TD1/0=0b11:minutes
    Wire.write(0b00000001);     // every 1 minuts
    Wire.endTransmission();
}

// interrupt occurs every 8 hours
void RTC8564::INT8hours(void)
{
	uint8_t Hours8;
    delay(10); //cut&try
    // read minutes
    Wire.beginTransmission(RTC8564_SLAVE_ADRS);
	Wire.write(0x04);			// write reg addr 04 = Hours
	Wire.endTransmission(false);
	Wire.requestFrom(RTC8564_SLAVE_ADRS, 1);
    Hours8 = Wire.read();
    Hours8 = ((Hours8 & 0x3f) >> 4) * 10 + (Hours8 & 0x0f);   // BCD --> decimal
    Hours8 = Hours8 + 8;
    if ( Hours8 > 23){
        Hours8 = Hours8 - 24;
    }
    Hours8 = (((Hours8 - (Hours8 % 10))/10) << 4) | (Hours8 % 10);

    Wire.beginTransmission(RTC8564_SLAVE_ADRS);
	Wire.write(0x0E);			// write reg addr 0E "Timer Control"
    Wire.write(0b00000000);     // TE=0 Timer Disable
    Wire.endTransmission();

    Wire.beginTransmission(RTC8564_SLAVE_ADRS);
	Wire.write(0x01);			// write reg addr 01 "Control 2"
    Wire.write(0b00000010);     // TI/TP=0, AIE=1, TIE=0, Clear AF bit
    Wire.endTransmission();

	Wire.beginTransmission(RTC8564_SLAVE_ADRS);
	Wire.write(0x09);			// write reg addr 0F "Timer"
    Wire.write(0b10000000);     // mask Minute Alarm
    Wire.write(Hours8);         // Hour Alarm ( now Hours + 8 hours)
    Wire.write(0b10000000);     // mask Day Alarm
    Wire.write(0b10000000);     // mask Weekday Alarm
    Wire.endTransmission();
}

// interrupt occurs on 4 o'clock
void RTC8564::INT4oclock(void)
{
    delay(10); //cut&try

    Wire.beginTransmission(RTC8564_SLAVE_ADRS);
	Wire.write(0x0E);			// write reg addr 0E "Timer Control"
    Wire.write(0b00000000);     // TE=0 Timer Disable
    Wire.endTransmission();

    Wire.beginTransmission(RTC8564_SLAVE_ADRS);
	Wire.write(0x01);			// write reg addr 01 "Control 2"
    Wire.write(0b00000010);     // TI/TP=0, AIE=1, TIE=0, Clear AF bit
    Wire.endTransmission();

	Wire.beginTransmission(RTC8564_SLAVE_ADRS);
	Wire.write(0x09);			// write reg addr 0F "Timer"
    Wire.write(0b10000000);     // mask Minute Alarm
    Wire.write(0x04);           // Hour Alarm ( set 4 o'clock)
    Wire.write(0b10000000);     // mask Day Alarm
    Wire.write(0b10000000);     // mask Weekday Alarm
    Wire.endTransmission();
}

void RTC8564::begin(void)
{
	//Wire.begin(4,5);
	if(isvalid() == false)
		init();
}

void RTC8564::sync(uint8_t date_time[],uint8_t size)
{
	Wire.beginTransmission(RTC8564_SLAVE_ADRS);
	Wire.write(0x00);			// write reg addr 00
	Wire.write(0x20);			// 00 Control 1, STOP=1
	Wire.endTransmission();

	Wire.beginTransmission(RTC8564_SLAVE_ADRS);
	Wire.write(0x02);			// write reg addr 02
	Wire.write(date_time, size);
	Wire.endTransmission();

	Wire.beginTransmission(RTC8564_SLAVE_ADRS);
	Wire.write(0x00);			// write reg addr 00
	Wire.write(0x00);			// 00 Control 1, STOP=0
	Wire.endTransmission();
}
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

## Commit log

2025-01-11 1st commit
    [tempSensor-Body.stl, tempSensor.FCStd]
2025-01-11 Add schematics
